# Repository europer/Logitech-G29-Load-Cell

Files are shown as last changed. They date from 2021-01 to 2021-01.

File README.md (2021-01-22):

# Logitech-G29-Load-Cell

I will not repeat the text what you can find in the "References" and keep the story short:

My ideas to develop this program was due to the inspiration and using the ideas of the References:

# References
1) https://github.com/GeekyDeaks/g29-load-cell (original idea did come from here)
2) https://github.com/Skidude88/Skidude88-G29-PS4-LoadCell-Arduino/wiki (original idea did come from here)
3) https://github.com/olkal/HX711_ADC (library for the HX711 I did use)
4) https://github.com/iforce2d/thrustTester (to get the default setup of the HX711 from 10 to 80 Hz, my HX711 did end up with 89 Hz)
5) https://circuitjournal.com/50kg-load-cells-with-HX711 (wiring with 2 cells)
6) https://www.youtube.com/watch?v=iywsJB-T-mU (at 7:15, due to ESP32 speed)
7) https://www.youtube.com/watch?v=99u9cy7Mnl4 (for mod the rubber to simulate more like a load cell)
8) Google Store: Serial Bluetooth Terminal from Kai Morich
9) Gamma Calculation: https://www.desmos.com/calculator/swnathc6og

and I will not refer it more in the text, since it is a mix overall and all of them above did contribute to my result.

The reason for this is that the G29 use pot.meter from 0-100% break over distance => give the output voltage to regulate corresponding break %.
The force feedback from the spring is more or less linear and at the end we touch a rubber what will simulate a higher pressure but for the muscle memory is difficult to memorize the breaking point/level/force to get a constant good breaking especially in trail breaking is difficult. 
With a load cell we are simulating closer to real hydraulic breaks in real life where we need over proportional force curve to reach higher break.

Then the G29 and PS4 do not give any possibilities to trim the break to your driving style and this was also one of my reason to have a micro controller so that I could manipulate the output values to fit my braking conditions.

# Shopping List:
1) Load Cells with HX711 
2) Micro controller 
3) Enclosing for the Micro Controller/HX711 and for the Load Cells
4) Resistors (500 and 220 Ohm) and cables

# How-to and why

To use PWM signal to generate the needed voltage range was not good if not using a low filter or a DAC. Since I am using ESP32 anyway to other Arduino projects and they are cheap (at Amazon go under 6 Euro, included delivery) is a very unexpensive MC.

The advantage:
1) rel. fast 2xCPU with 32 bits
2) 2 x8 bit DAC (range 0-255)
3) Bluetooth for serial com. for changing parameters in the setup/trimming the break
4) Voltage range 0-3.3V fits anyway to the G29 what also is in this range

That was the reason to use ESP32 and as I was work with the project I wanted to "simulate" a "PWM" with my DAC between 2 values and here the multitask function of the ESP32 was perfect, letting the main program calculate the values for breaking and if a needed value was between, let’s say 231 and 232 I would let the DAC jump between 231 and 232 in an constant loop (of course calculated how many times of 231 and 232 to get the right simulated value let say 231.12) so in this case the task would not have any "delay" but just looping and looping with the latest known values until the task did get new values. Fantastic the ESP32 :)

Another issue known is that the G29 let’s say your breaking at 80% distance on the break is not equal to 80% in your PS4. G29 have an over exponential curve and I had to find out the values so that I could do a linearization of the curve (also my references are referring about this issue). After finding 0% break and 100% I had the outer points (min/max). So, 50% must be between, well was not as explained above. How to find 50%? I did find the bit value what was correspond to 50% in the game. Let’s say 0% was 210 and 100% 140 => (140+210)/2 = 175 in the DAC as bit but was not. So, you then change the bit value until you get the 50% in the game (look at the TV/Monitor and adjust the bit value until you see the column reach 50% in my case GT Sprot). So now the work was to check for many different %-point between 0 and 100% after this I could make a load array, you could also use a function but is quicker to use points in an array and calculate the output between 2 points.

Then I wanted to have a gamma factor to adjust the bias of the curve to fit my way of breaking. 
G>1.0 means that the break% is increasing over proportional, G<1.0 the opposite. G = 1 linear.

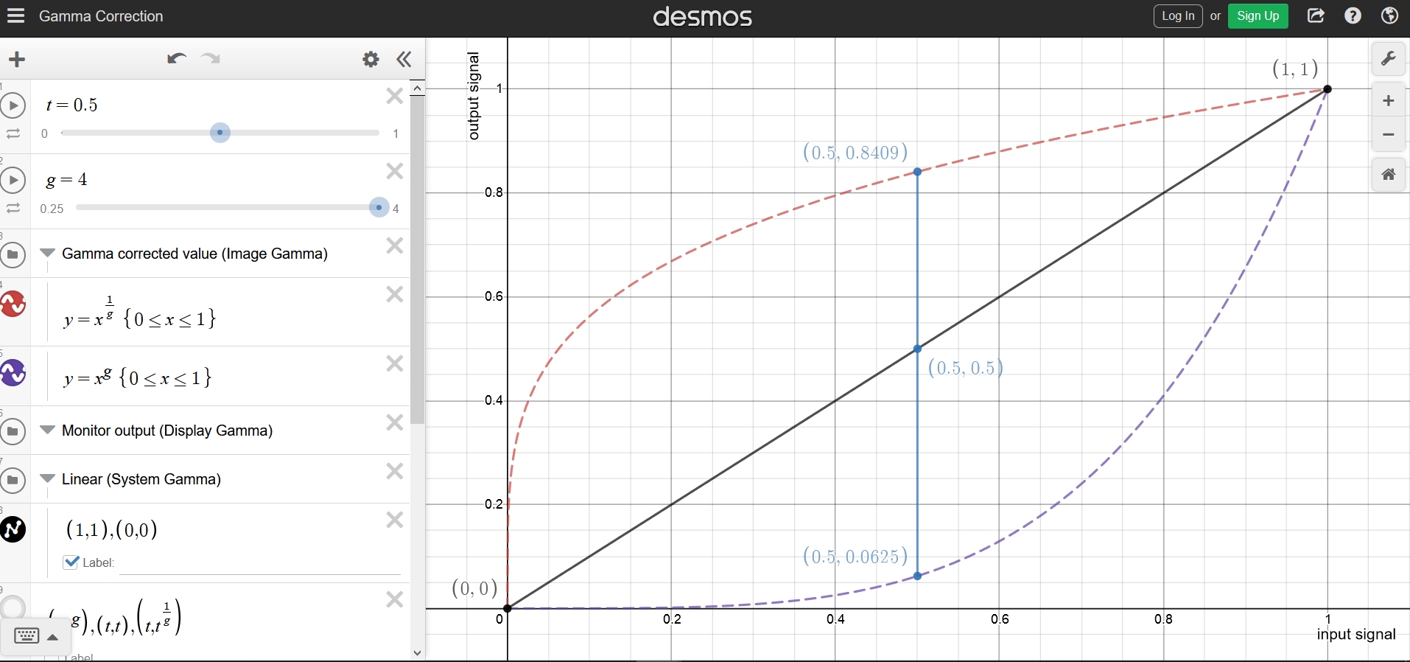
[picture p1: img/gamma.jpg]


Pic. 0) see References #9, Gamma Calculation: https://www.desmos.com/calculator/swnathc6og. 
Red dotted line gamma = 4, Blue dotted line gamma = 0.25 and black line gamma = 1 = linear

Then the break needed a dead zone, means your break don’t start at zero Kg but at example 0.2 Kg.
Then the break needed a max load = 100% break, so if you hit the break more than max load => 100% break.
Then I did read in IRacing that the max load = 100% could be reduced to a %, let’s say 80%, means if you break at max load = 100% (normally) it would be 80%, so I also implemented this (never know if I will do IRacing but anyway good to have).
Then I wanted to send over the air serial commands to the ESP32 to change parameter for my breaking if trimming was needed during the race (rather between the race or qualifying).
Then of course encloser for the brake system and for the ESP32/HX711 (see 3D files)

That is all in a nut-shell.

Im an engineer and not a programmer so could be that my programming is dirty, so I do not mind if somebody would pimp it up, but it works and it works like a charm.

# Circuit/Wiring/PCB

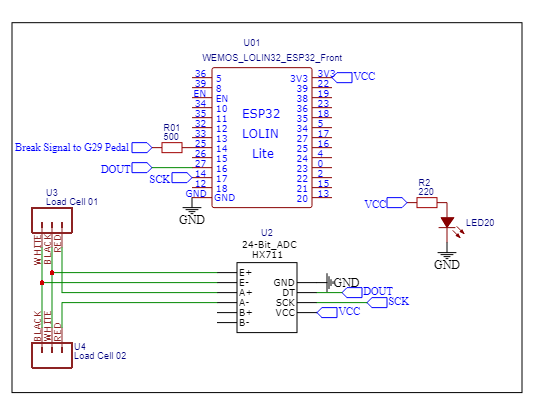
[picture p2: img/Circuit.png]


Pic. 1) See Ref. 5) https://circuitjournal.com/50kg-load-cells-with-HX711 (wiring with 2 cells)

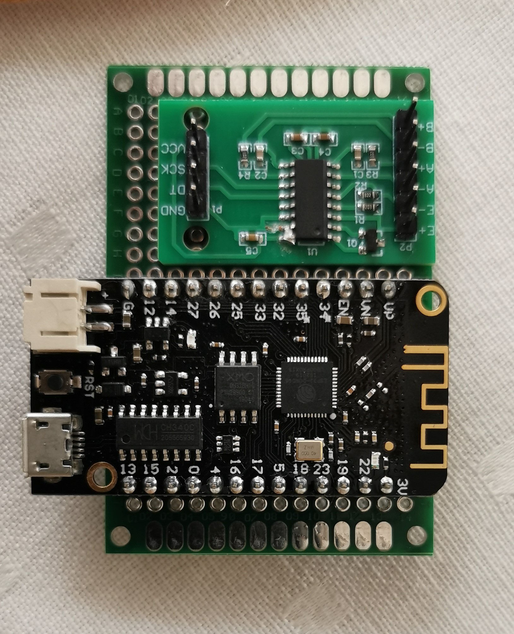
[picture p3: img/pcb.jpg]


Pic. 2) Soldering ESP32 & HX711 on a small PCB, wiring after circuit diagram (see Pic. 1 above)

# 3D Print / Encloser

yes, I know old filament so not the nicest but did work perfect anyway ;)

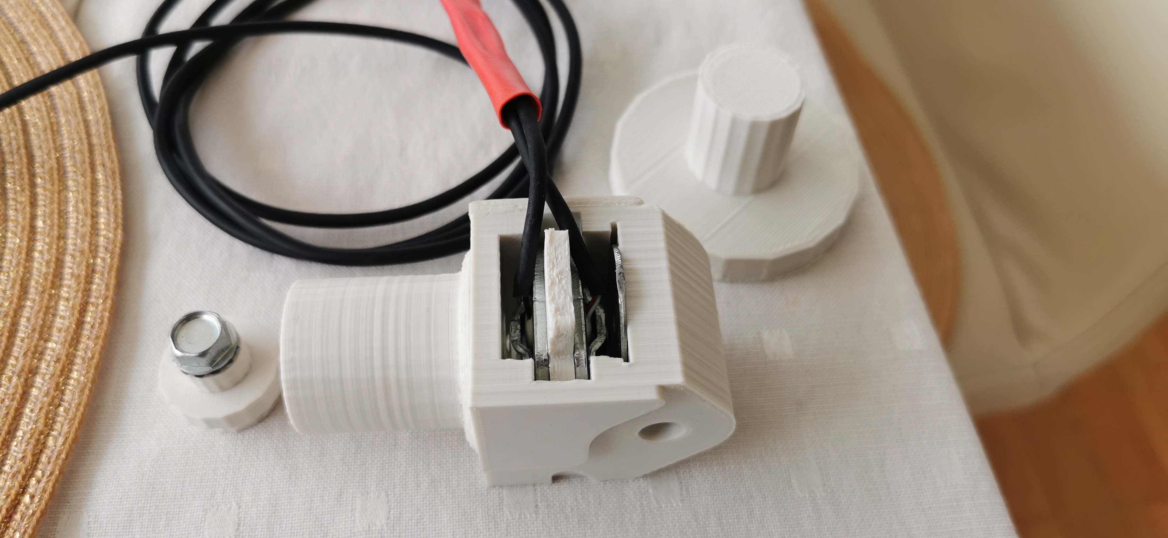
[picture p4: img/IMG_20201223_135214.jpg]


Pic. 3) left part: plunger what is pushing the load to the load cell, mid part = encloser for the 2 load cells, right part = calibrator (see Pic. 4)

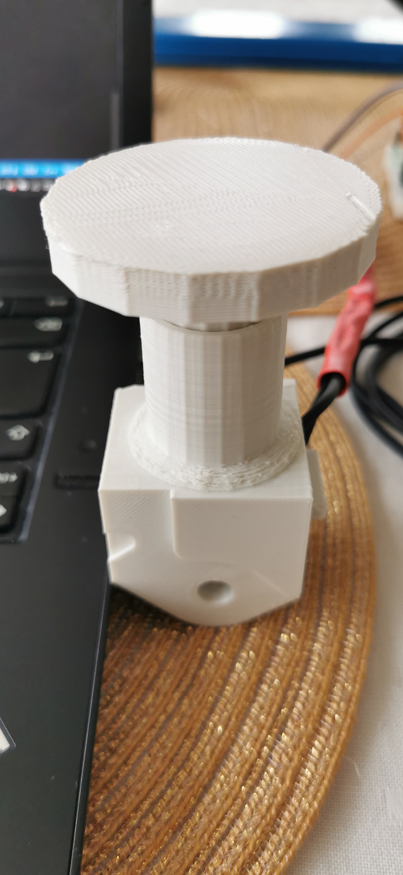
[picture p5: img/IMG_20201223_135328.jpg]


Pic. 4) the Calibrator is just to have a platform to put load on as one-time calibration for weight. I did use 2x1Kg as reference 

# STL Files for the Break and for the ESP32 Box:

See folder STL_BREAK and STL_BOX:
https://github.com/europer/Logitech-G29-Load-Cell/tree/main/STL_BOX
https://github.com/europer/Logitech-G29-Load-Cell/tree/main/STL_BREAK

# Linearization Results:

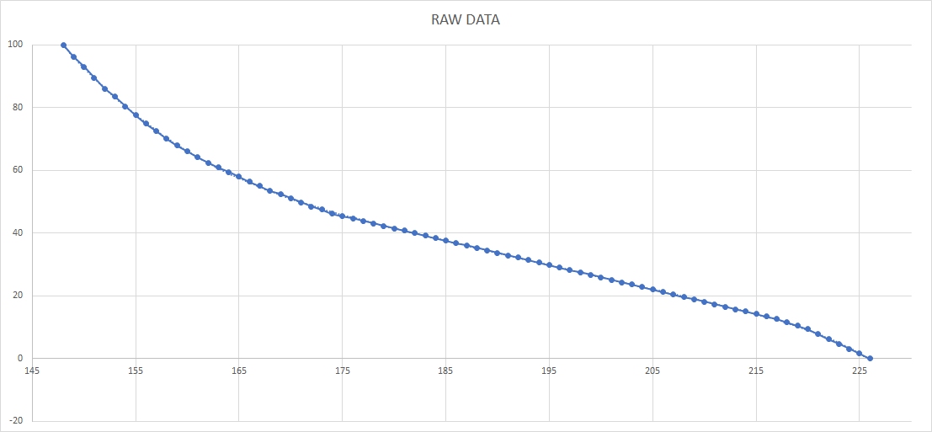
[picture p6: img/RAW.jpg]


Pic. 5) The result of the raw data in a diagram. Y: Break force [%] X: Voltage in 8 Bit (0-255 = 0-3.3V)

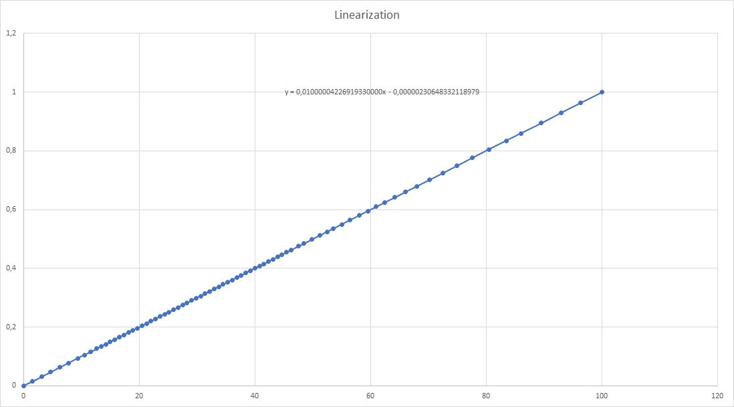
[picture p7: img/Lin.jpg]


Pic. 6) From Pic 5 the Load was linearized (from 0-1 and 0-100%) so that 50% load input = 50% break in game.

The load array (is in the Arduino program) resulted into the following load array with 79 points:

float load_percent[79] = {1.0, 0.963, 0.93, 0.895, 0.86, 0.835, 0.804, 0.776, 0.749, 0.725,
                          0.701, 0.68, 0.66, 0.642, 0.625, 0.609, 0.595, 0.58, 0.564, 0.55,
                          0.535, 0.525, 0.512, 0.498, 0.485, 0.475, 0.462, 0.455, 0.447, 0.439,
                          0.431, 0.423, 0.416, 0.408, 0.4, 0.392, 0.384, 0.377, 0.369, 0.361,
                          0.353, 0.345, 0.337, 0.33, 0.322, 0.314, 0.306, 0.298, 0.291, 0.283,
                          0.275, 0.267, 0.259, 0.252, 0.247, 0.236, 0.228, 0.220, 0.212, 0.205,
                          0.197, 0.189, 0.181, 0.173, 0.166, 0.158, 0.15, 0.142, 0.134, 0.127,
                          0.116, 0.105, 0.094, 0.078, 0.063, 0.047, 0.031, 0.016, 0.0};
                          
How to understand this:
We have after calibration the min and max point/break: 
min break = 147 and max break = 227 in voltage this again correspond to a weight from your load cell, let’s say:
min break = 1.0 Kg and max break = 10.0 Kg.

We now map the input (what is the kg) to output what we need to as voltage out to correspond to the weight/force:

Let’s say we are pushing with a force of 5.5 kg.

In the program this we use the mapping function:
Syntax: mapping(weight in,min break kg, max break kg, min output, max output). //own function, yes you can use the map what Arduino have, but sometimes I like my own routines.

weight_in_percent = mapping(5.5, 1.0, 10.0, 0.0, 1.0) and yes output will be 0.50 in this case ;).

From the load_percent array 0.50 is between nr 22 = 0.512 and nr 23 = 0.498 (counting with 0 as first value), the program will loop trough the array to see where weight_in_percent. 
The laod_perecent range is 79 points and the max/min break from 147 to 227 = 80, not same steps so we need to map this too.

lower = mapping(22, 78, 0, 227, 147) = 170.
upper = mapping(23, 78, 0, 227, 147) = 169.

Mean when the ESP32 send a DAC with the bit 170 and 169 we would get 50% break load, without the linearization the program would send out (147+227)/2 = 187 to DAC.
If we look at Pic. 5 this would result into approx. 37% breaking and not 50%.

The program calculates out of 10 how many times it must be lower and upper so that the task (FreeRTOS) to "simulate" a PWM between 2 DAC signal. 
In this case it would be 8 times 170 and 1 time 169 due to rounding.
If there is no new update from the load cell or/and the load value is the same it will just loop and loop these values until new values comes in.
Since this task operate without interference there are no timer since the task will be relative constant in time and performance.
Later in text you can see a short video from the oscilloscope and simulate a sinus curve and we will see that for this application is more the good enough.

In Arduino, DAC1 = Pin 25 for ESP32 (see ESP32 reference, DAC1 = 25, DAC2 = 26):.
dacWrite(DAC1, 170); x 8 times. 
dacWrite(DAC1, 169); x 1 time.

In this video (sorry was a video for my father-in-law and he is a master in electronic and it was in Norwegian).
we see the first part with Gamma factor = 1 (linear) then with Gamma 4.0 and then with Gamma = 0.25.

https://github.com/europer/Logitech-G29-Load-Cell/blob/main/img/Osci.mp4

# AoB

I did cut the outer valve 10mm because due to shorter distance due to the new inner valve (where the load cell is installed into) takes space in direction to the pedal I personally needed 10mm more. 
I did also increase the original rubber as in Reference 7) https://www.youtube.com/watch?v=99u9cy7Mnl4 (for mod the rubber to simulate more like a load cell).
Here you need to find your length of the rubber you need, I did increase my new "rubber" so that I had 1,5times the length from the original, but after cutting the 10mm above it was then to short, rather 2times would be better. The reason is very weak spring, first when I hit the rubber the weight goes high. I do compensate this with a Gamma of 1.8 but I will further change the spring to a lot stiffer version. This part everybody needs to find at its own and I can’t give any preference what is good or bad, since this is individual.

Regards the libary, in PlatformIO my local libaries are (default) in hidden folders, so as I did upload everything thouse files did not go into my github, therefore I did save them in the folder "lib". You just download them and put it where you need it in you libary system, you need perhaps to change the #inlcude from "....." to #inlcude from <.....> and then it should work for all IDE's

Did it help me, YES, my lap time did reduce in average up to 3 sec and not just that, my laps are constant, less errors in general, so for around 15 Euro investment a great update, I think the best update you can do for sim racing!!!

# Using the serial commands

over USB or BT, see Reference 8) Google Store: Serial Bluetooth Terminal from Kai Morich.
1) t = for TARA the load cells.
2) c = for calibrate the load cell, pushing pedal to your desired max break and 2nd push for min break.
3) v = for voltage calibration (max break and min break, it use the dacWrite(DAC1, wanted bit for min or max break)).
4) e = read out the storage values in the eeprom since mostly we will not change values and just play the game when we have the wanted parameter ;).
5) a = read out what is in RAM at given time, if you use "e" to read out eeprom it will change the values in the RAM if they could be different, since you dont need to save new values!!!.
6) w = in BT-App and www = at direct conection between ESP32 and PC. Here we calibrate the load cell with known load, use the calibrator (see Pic. 4) and put know load on it, I was using 2x1kg manuall weights, but you can also use a liter of water, or 1 kg Sugar, what ever. This is just to know for your interesst what is acctually the load in Kg but is not needed, but you need to but a value here for the first time. If you dont have a refrence value push a bit, and give 1000 in (what would be normaly 1000g=1kg).
7) s = to have serial output of the load your have at given time (every 1 sec an new serial.print).
8) l = here you can fine tune your 'c' directly into kg (max/min).
9) r = reboot the ESP32.
10) n = using the raw data or noralisation with gamma factor.
11) i = simulate 1=sinus curve, 2=0,25,50,75,100% load and default is 0 what is the load cell itself.

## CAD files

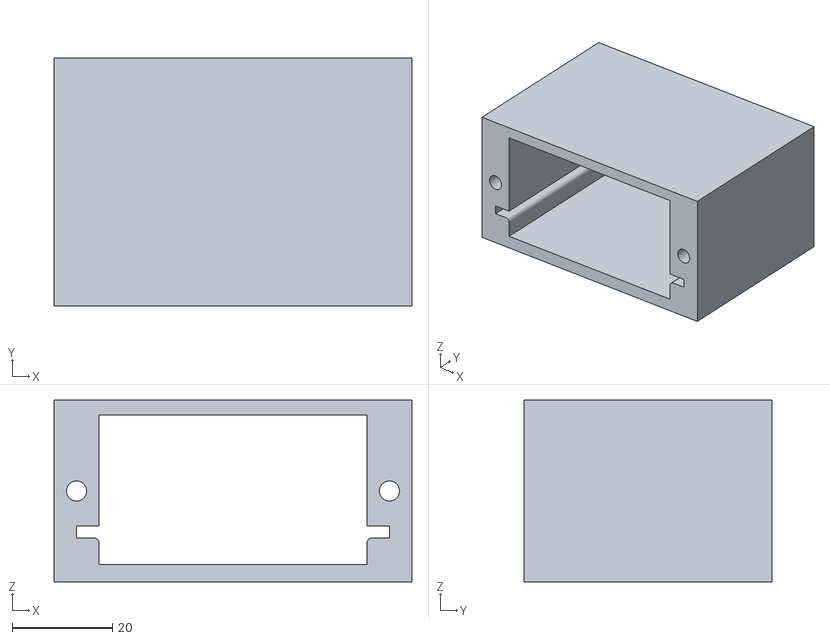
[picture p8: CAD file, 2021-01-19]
STL_BOX/Box_Main_V02.stl
71.5 x 49.6 x 36.3

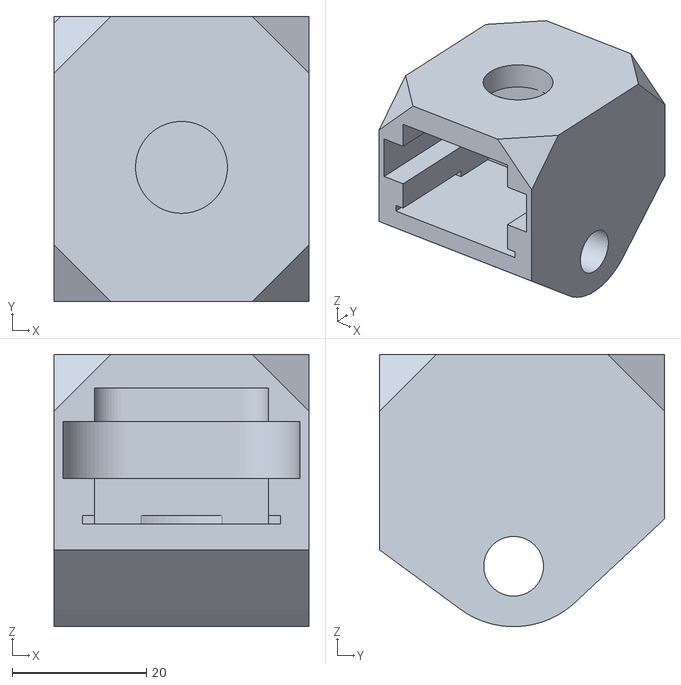
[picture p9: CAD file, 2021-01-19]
STL_BREAK/main_body_V06.stl
38.0 x 42.5 x 40.6

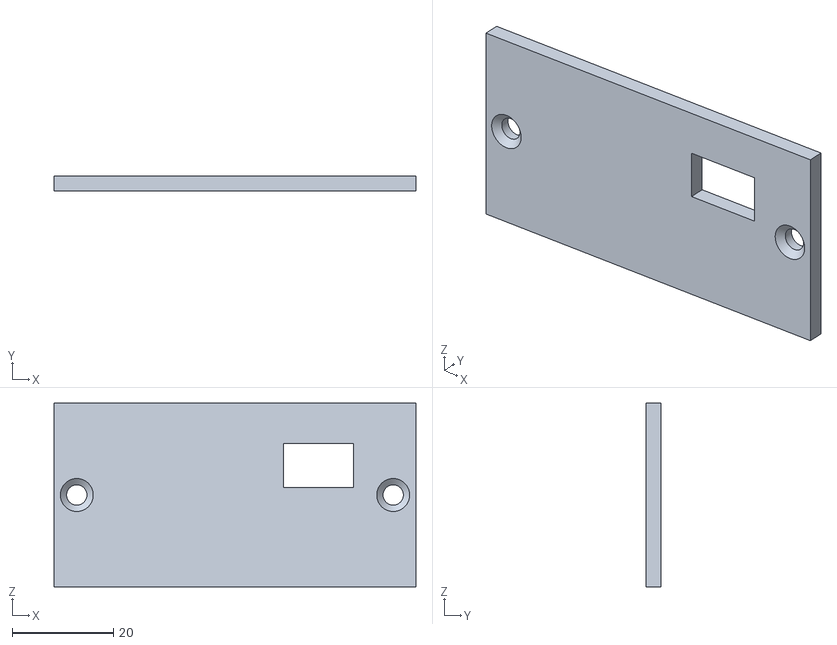
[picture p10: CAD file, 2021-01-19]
STL_BOX/Box_Front.stl
71.5 x 3.00 x 36.3

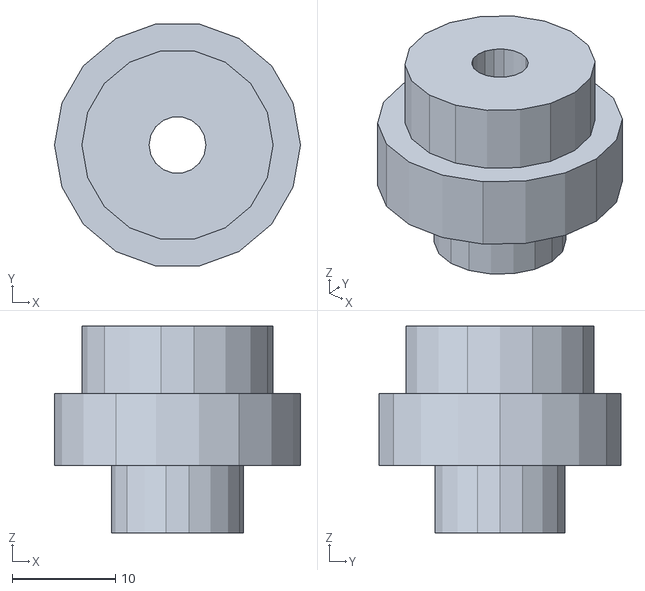
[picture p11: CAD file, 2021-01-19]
STL_BREAK/plunger.stl
23.8 x 23.4 x 20.0

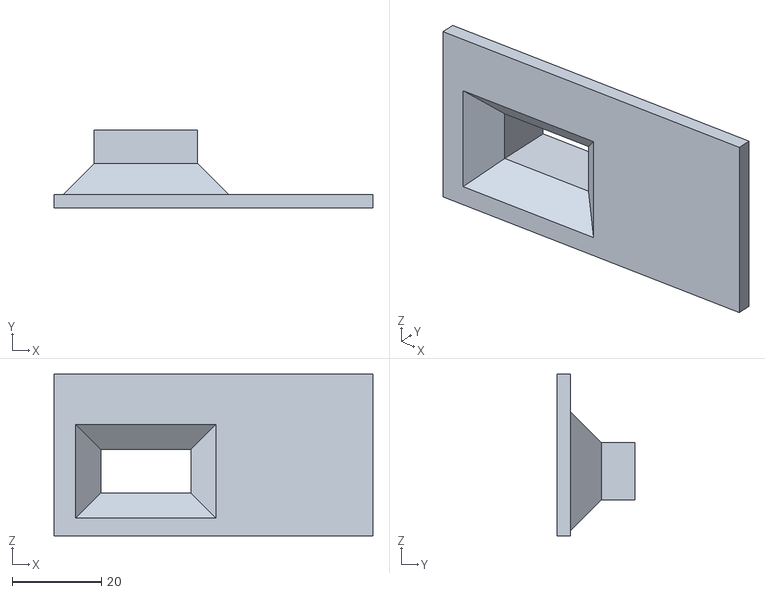
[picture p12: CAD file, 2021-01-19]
STL_BOX/Box_Back_V03.stl
71.5 x 17.5 x 36.3

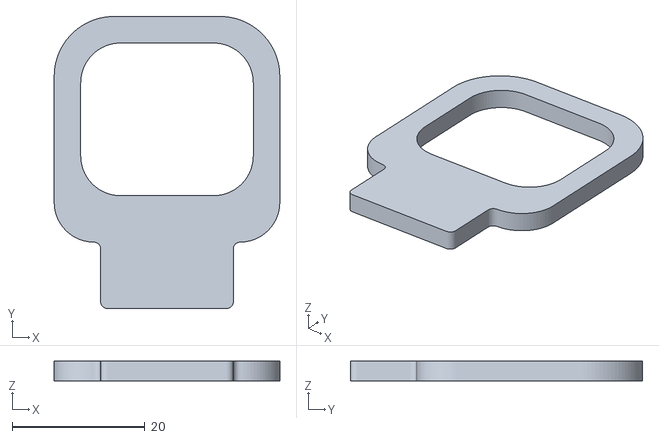
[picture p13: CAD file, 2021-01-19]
STL_BREAK/spacer_V06.stl
34.0 x 44.0 x 3.00

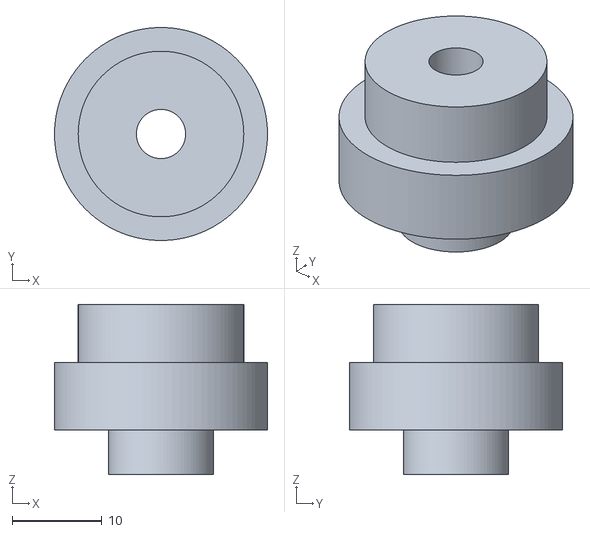
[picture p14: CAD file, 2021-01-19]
STL_BREAK/plunger_V07.stl
23.8 x 23.8 x 19.0

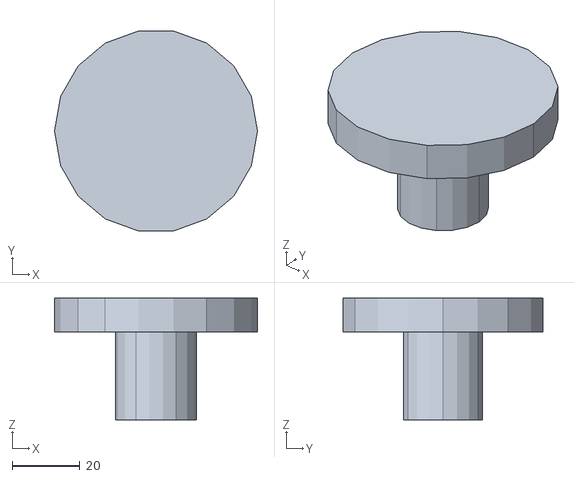
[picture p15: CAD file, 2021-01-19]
STL_BREAK/calibrator.stl
60.0 x 59.1 x 36.0

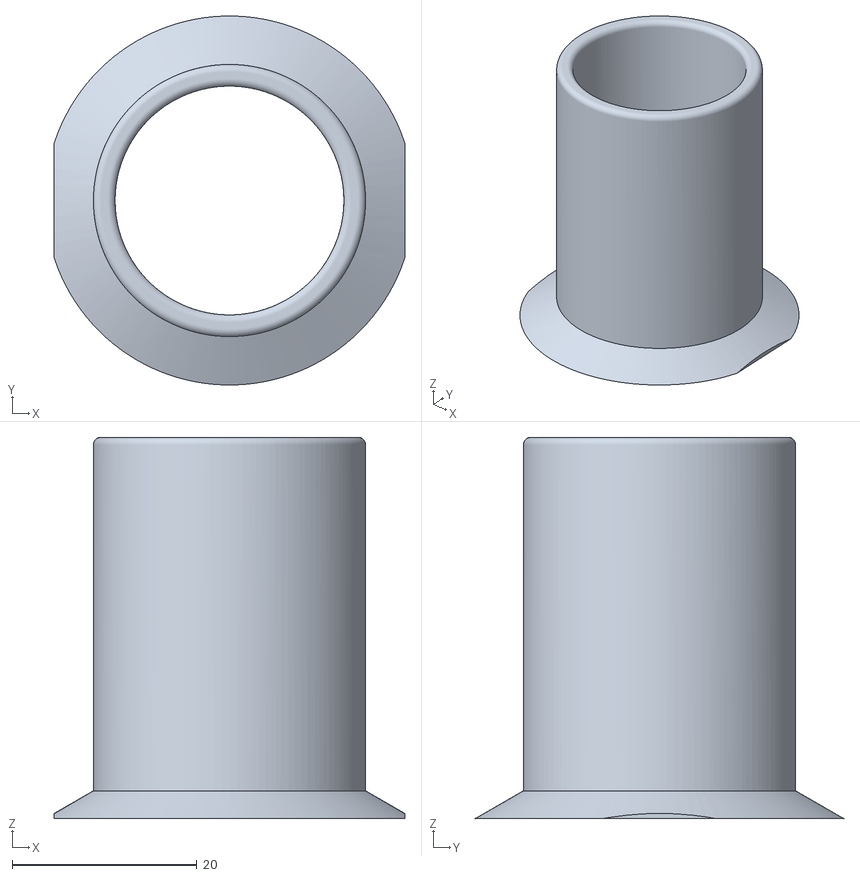
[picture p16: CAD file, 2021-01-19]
STL_BREAK/cylinder_V06.stl
38.0 x 40.0 x 41.4

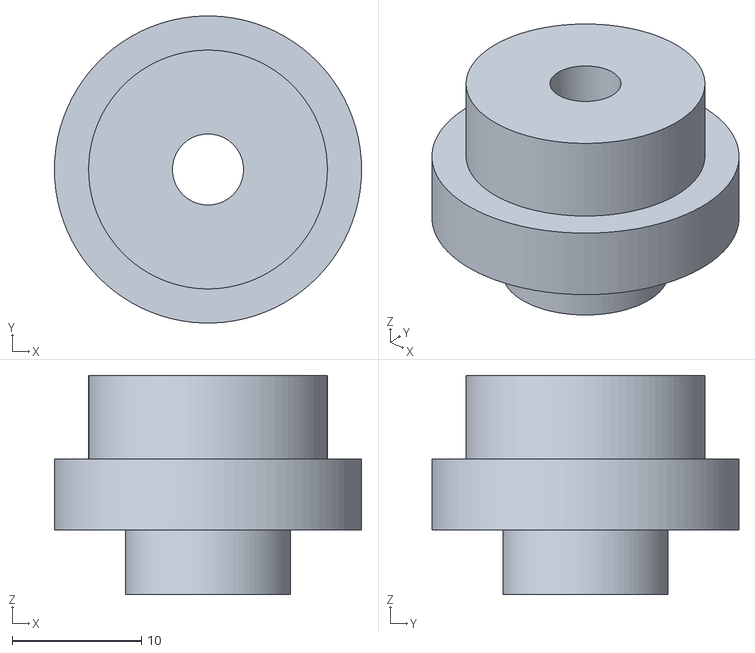
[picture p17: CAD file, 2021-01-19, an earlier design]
STL_BREAK/plunger_V06.stl
23.8 x 23.8 x 17.0

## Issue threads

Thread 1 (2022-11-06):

How to asseble printed parts?

freestaila, 2022-11-06:
Hi!

First of all I would like to thank you for sharing this awesome project!
I have a questions about this printed files.
1. One part of the box have holes for screws. The bottom one don't. I should glue this bottom part or just need to drill this holes manually?
2. The center part - cylinder is separrated part. On other projects this is one part with this main part for cells. Is it only for first calibration and I should only use this part with screw to make pressure for cells? I'm not sure how to mount this to the origin setup.

Thanks for the answers!

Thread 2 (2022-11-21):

Function calicalulation_break() no return

freestaila, 2022-11-21:
Hi!

Inside `calicalulation_break()` function return is missing for calc_type 1.
That causing problem with calibrate function. After put value for max break point program breaks.

europer, 2022-11-22:
Hi,
the code I did write for x years back so I am not more into it, but will have a look and see if the uploadet data here in github is the same as on my ESP32 and come back to you if its a quick fix for this issue.
BR

europer, 2022-11-22:
I had a very brief look at the code, surly now I would code it a bit differently but never the less it should work also without return.If you need to but a return just put reutrn -10 or a integer, since the only thing what I wanted with this function was this:
int calicalulation_break(float &value2change, float value2compare, int flag2compare, int calc_type)
and what I want is the "float &value2change" back from the function. I passed the value into function, the return value have no meaning.
I could be at calibration the value from you system is not ok. In case of case 1 you need to be between max and min load at least 90% so that the min value is lower and also min<max*90%. Have you checked the load data from your load cell?

But again, if you but some returns into the code for the case 1 (as in case 2) and this makes the calibration correct, then its fine.

Again, I will look at my last code in my pc and see if this is the same version as into github

cheers

europer, 2022-11-22:
ok, I would change the function today like this:

int calicalulation_break(float &value2change, float value2compare, int flag2compare, int calc_type)
{
the code of the functuon
and extra at the end of the function
return -1;
}

what ever reason after all "if" and no conditions are meet or no return at least one return will be trigger.
since the return value have no meaning, could be as I was programming that time I had an idea of something. I mean it could also be a void function but never the less just put a return (int) at the end of the function.
In the main program the function is never uses like this (example)

returnvalue = calicalulation_break(maxbreak, 0, 0, 1);

but just like this:
calicalulation_break(maxbreak, 0, 0, 1); becasue I just wantend the (in this case) the maxbreak value as "return"

I hope this helped (not forget was my first project and I am not a c/c++ expert ;) ) so surly dirty coding ;)
(but did work without problems all the years, perhaps luck? ;) )

freestaila, 2022-11-22:
@europer thanks for the answer. I already fixed it for me and I have proper calibrations values. All set up with cells and esp32 works good for now.

I don't know why but after connecting board to logitech wires- it seems like unstable power connection. Light on board switcing off and on second by second. I connected 2 reds and 2 blacks to micro usb cable.

Of course this code is not perfect but works! Thats matters. Hope I will finish my setup soon.

freestaila, 2022-11-22:
One more question.
I connected to Logitech brake wires micro USB cable to provide power to board. But without USB I have 3.3v output after connect via USB to board I have 1.7v. Do you connected power wires to board directly?

europer, 2022-11-24:
Good question and I see I have formulated less here in my GitHub. But here how I did it. My esp32 get power from a usb adapter. All pedals got the power normal from Logitech, just the break got the signal from the esp32, but common earth (of course) so you have look at the potensometer on break and take the signal line to esp32 setup. So the esp32 setup is the new potesiometer. I hope you got me?
BR

europer, 2022-11-24:
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

europer, 2022-11-24:
There is 3 cables at the break. 1) VCC u don't need 2) output cable you need to connect to output signal on esp32 and 3) ground  cable on pedal and esp32

freestaila, 2022-11-24:
Ground only need to be connected to esp32? Or both to the brake and ESP?

freestaila, 2022-11-24:
Output is white? Now when I use throttle brake also works hahah

freestaila, 2022-11-24:
And brake no

europer, 2022-11-24:
Do u have voltmeter, chech where the 3.3v and where the signal line is on the potensometer. Regards ground, so long you use the ground cable what was on the pedal to connect to esp32 ground it would be enough but the pedal have lot of mass so I just mean it the better ground, but is not necessary because the cable is anyway ground from Logitech

europer, 2022-11-24:
Strange, check all connection not that you have some connections to trottle, chech also it the contact from pedal into the wheel is properly in. Check also you esp32 output makes voltage between 0-3.3v. it's just a intelligent potensometer where you can manipulate values. It is really nothing else

freestaila, 2022-11-28:
When normalization is set to 0 all looks good. When I change this to 1 then my values on serial are good for weight but Voltage is always = 3.3V. Something goes wrong inside calculation for nromalization.

europer, 2022-11-30:
It's strange since it works flawlessly on my esp32
I can't say what it is.
Chech without the Normalisation and if u push break to 50% (that time it was on GT sport) your game your playing what is the result.
You need to calibrate your cells to your game.
You need to know at witch voltage zero break is.
You need to know at witch voltage at 100% break is.
So if you know this you know that between 0 and 100% where the voltage for 50% what should be 50% breaking force but mostly this will not be in the game. Therefore we do the Normalisation. To recalc that when we "push" 50% you get 50% in the game but as in my test in GitHub you need check if this fits for your game, load cell ..
BR

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

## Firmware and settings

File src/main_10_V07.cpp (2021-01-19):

#include <Arduino.h>
#include <math.h>
/*
   -------------------------------------------------------------------------------------
   HX711_ADC
   Arduino library for HX711 24-Bit Analog-to-Digital Converter for Weight Scales
   Olav Kallhovd sept2017
   -------------------------------------------------------------------------------------
*/

/*
   This example file shows how to calibrate the load cell and optionally store the calibration
   value in EEPROM, and also how to change the value manually.
   The result value can then later be included in your project sketch or fetched from EEPROM.

   To implement calibration in your project sketch the simplified procedure is as follow:
       LoadCell.tare();
       //place known mass
       LoadCell.refreshDataSet();
       float newCalibrationValue = LoadCell.getNewCalibration(known_mass);
*/

//own local libaries
#include "string2char.h"    //convert string to char
#include "bit_check_band.h" //check if a value is within the min max if lower=min, if over=max
#include "mapping.h"        //map a input value to a new range out

// external libaries
#include <HX711_ADC.h> // the libary for the HX711
#include <EEPROM.h>    //Libary for the EEPROM Memory
#include <BluetoothSerial.h>

#if !defined(CONFIG_BT_ENABLED) || !defined(CONFIG_BLUEDROID_ENABLED)
#error Bluetooth is not enabled! Please run `make menuconfig` to and enable it
#endif

BluetoothSerial SerialBT;

TaskHandle_t Task0;
//TaskHandle_t Task1;
//QueueHandle_t queue;
SemaphoreHandle_t Semaphore;

//pins:
const int HX711_dout = 27; //mcu > HX711 dout pin
const int HX711_sck = 14;  //mcu > HX711 sck pin

//DAC output
#define DAC1 25 // Break Voltage Out to PS4/PC

//HX711 constructor:
HX711_ADC LoadCell(HX711_dout, HX711_sck);

const int calVal_eepromAdress = 0;
long t;

long t_simulate;
int flag_init_time = 1; //1=true
int case_counter = 0;

String ino = __FILE__; //file name

bool volt_direction_normal = false; // break 0-100% voltage low-hight = true

float max_break = 21.23f;
float max_break_redfac = 100.00f; //if max break to much reduce here in %
float min_break = 1.43f;

//max voltage in esp32 is 3.3volt and adjust the break in the PC/PS4
/*
  GTSport
  break 0% - 2.86v = 221
  break 100% - 1.93v = 149
  Assetto Corsa Comp
  break 0% - 2.88v = 222-223
  break 100% - 1.48v = 114
*/
int min_break_volt = 221;
int max_break_volt = 149;

int minbit = 0;
int maxbit = 255;

float esp32Volt = 3.3;

float ref_voltage = (1.0 / 255.0) * esp32Volt;

float newCalibrationValue = 1.23f;

float kg_factor = 1000.0f;

int SerialPrintData = 0; //no Serial Printout of Data

bool reboot_esp32 = false;

int simulant_case = 0; //no simulation just the load cell, Sinus curve = 1, na=2, na=3

float gammafac = 1.0; //linear
int laod_percent_steps = 79;
float load_percent[79] = {1.0, 0.963, 0.93, 0.895, 0.86, 0.835, 0.804, 0.776, 0.749, 0.725,
                          0.701, 0.68, 0.66, 0.642, 0.625, 0.609, 0.595, 0.58, 0.564, 0.55,
                          0.535, 0.525, 0.512, 0.498, 0.485, 0.475, 0.462, 0.455, 0.447, 0.439,
                          0.431, 0.423, 0.416, 0.408, 0.4, 0.392, 0.384, 0.377, 0.369, 0.361,
                          0.353, 0.345, 0.337, 0.33, 0.322, 0.314, 0.306, 0.298, 0.291, 0.283,
                          0.275, 0.267, 0.259, 0.252, 0.247, 0.236, 0.228, 0.220, 0.212, 0.205,
                          0.197, 0.189, 0.181, 0.173, 0.166, 0.158, 0.15, 0.142, 0.134, 0.127,
                          0.116, 0.105, 0.094, 0.078, 0.063, 0.047, 0.031, 0.016, 0.0};

float rad = 0.0; //zero angle

int normal = 1; // 2 = use input as output (raw with oth load_percen array), 0 = in voltage

// Global variables, available to all
static volatile unsigned int lowerbitcase;
static volatile unsigned int upperbitcase;
static volatile unsigned int lower2pwm;
static volatile unsigned int upper2pwm;
static volatile bool open2use = false;
static volatile unsigned long count = 0;
static volatile int normalization = 1;
static volatile float GLED_global;
static volatile int dac_case_global;

void print_serial_and_bt(String text2print, int newlineornot)
{
    if (newlineornot == 0)
    {
        Serial.print(text2print);
        SerialBT.print(text2print);
    }
    if (newlineornot == 1)
    {
        Serial.println(text2print);
        SerialBT.println(text2print);
    }
}

void pause_multitask()
{
    //This is just during when we interact with the program with commands (serial commands)
    //until we are not finished the process with the commands the program stop the task

    //give the normalization = 2 => pause
    xSemaphoreTake(Semaphore, portMAX_DELAY);
    normalization = 2; //turn of multi task part of voltage in pwm2dac function
    open2use = true;
    xSemaphoreGive(Semaphore);
    vTaskDelay(200); //0.2mil sec delay

    //tell multitask not to take variables
    xSemaphoreTake(Semaphore, portMAX_DELAY);
    open2use = false;
    xSemaphoreGive(Semaphore);
}

void restart_multitask()
{
    //This is just during when we interact with the program with commands (serial commands)
    //until we are not finished the process with the commands the program stop the task

    //tell multitask to take variables again an set normal back to original 0 or 1
    vTaskDelay(3000); //3 sec delay
    xSemaphoreTake(Semaphore, portMAX_DELAY);
    normalization = normal; //give back the normal 0 or 1 (0=raw input != output on G29, 1=adjusted so that 50% load in = 50% load out)
    open2use = true;
    xSemaphoreGive(Semaphore);
    vTaskDelay(200); //3 sec delay
}

void SDPrint()
{
    Serial.flush();   //clean buffer
    SerialBT.flush(); //clean buffer

    print_serial_and_bt("***", 1);
    print_serial_and_bt("SerailDataOutput?", 1);
    print_serial_and_bt("Send 'y' or 'n'", 1);

    boolean _resume = false;
    while (_resume == false)
    {
        LoadCell.update();
        if (Serial.available() > 0 || SerialBT.available())
        {

            char inByte = Serial.read();
            char BTByte = SerialBT.read();
            if (inByte == 'y' || BTByte == 'y')
            {
                SerialPrintData = 1;
                _resume = true;
            }
            else if (inByte == 'n' || BTByte == 'n')
            {
                SerialPrintData = 0;
                _resume = true;
            }
        }
    }
    Serial.flush();   //clean buffer
    SerialBT.flush(); //clean buffer
}

void simulation_esp32()
{
    Serial.flush();   //clean buffer
    SerialBT.flush(); //clean buffer

    print_serial_and_bt("***", 1);
    print_serial_and_bt("Simulate load cell load?", 1);
    print_serial_and_bt("0: real load cell", 1);
    print_serial_and_bt("1: sinus curve", 1);
    print_serial_and_bt("2: 100,75,50,25,0 % curve", 1);
    print_serial_and_bt("-1: no changes", 1);

    boolean _resume = false;
    while (_resume == false)
    {
        LoadCell.update();
        if (Serial.available() > 0 || SerialBT.available())
        {

            char inByte = Serial.read();
            char BTByte = SerialBT.read();
            if (inByte == '0' || BTByte == '0')
            {
                simulant_case = 0;
                _resume = true;
            }
            else if (inByte == '1' || BTByte == '1')
            {
                simulant_case = 1;
                _resume = true;
            }
            else if (inByte == '2' || BTByte == '2')
            {
                simulant_case = 2;
                _resume = true;
            }
            else if (inByte == '-1' || BTByte == '-1')
            {
                _resume = true;
            }
        }
    }
    Serial.flush();   //clean buffer
    SerialBT.flush(); //clean buffer

    print_serial_and_bt("***", 1);
    print_serial_and_bt("case was used: ", 0);
    print_serial_and_bt(String(simulant_case), 1);
}

void reboot_mc()
{
    reboot_esp32 = true;
}

void tara_load_cell()
{
    print_serial_and_bt("***", 1);
    print_serial_and_bt("Tara started", 1);

    LoadCell.update();
    LoadCell.tareNoDelay();

    print_serial_and_bt("Tara finished", 1);
    print_serial_and_bt("***", 1);
}

void load_variables_eeprom(int ja_nein)
{

    if (ja_nein == 1) //from EEPROM = 1, and from RAM = 0
    {
#if defined(ESP8266) || defined(ESP32)
        EEPROM.begin(512); // uncomment this if you use ESP8266/ESP32 and want to fetch the calibration value from eeprom
#endif
        int temp_adress = 0;
        EEPROM.get(calVal_eepromAdress, newCalibrationValue);
        LoadCell.setCalFactor(newCalibrationValue); // set calibration value (float)

        temp_adress += sizeof(newCalibrationValue);
        EEPROM.get(temp_adress, max_break); //get  max break

        temp_adress += sizeof(max_break);
        EEPROM.get(temp_adress, min_break); //get also mix break

        temp_adress += sizeof(min_break);
        EEPROM.get(temp_adress, max_break_redfac); //get also max reduced break factor

        temp_adress += sizeof(max_break_redfac);
        EEPROM.get(temp_adress, max_break_volt); //get also max voltage

        temp_adress += sizeof(max_break_volt);
        EEPROM.get(temp_adress, min_break_volt); //get also min voltage

        temp_adress += sizeof(max_break_redfac);
        EEPROM.get(temp_adress, normal); //Save also max break

        temp_adress += sizeof(normal);
        EEPROM.get(temp_adress, gammafac); //get also max reduced break factor

        print_serial_and_bt("", 1);
        print_serial_and_bt("*** EEPROM Read OUT ***", 0);
    }
    else
    {
        print_serial_and_bt("", 1);
        print_serial_and_bt("*** RAM Read OUT ***", 0);
    }

    print_serial_and_bt("", 1);
    print_serial_and_bt("Max break Kg: ", 0);
    print_serial_and_bt(String(max_break / kg_factor), 0);

    print_serial_and_bt("", 1);
    print_serial_and_bt("Min break RedFac %: ", 0);
    print_serial_and_bt(String(max_break_redfac), 0);

    print_serial_and_bt("", 1);
    print_serial_and_bt("Min break Kg: ", 0);
    print_serial_and_bt(String(min_break / kg_factor), 0);

    print_serial_and_bt("", 1);
    print_serial_and_bt("calibration value : ", 0);
    print_serial_and_bt(String(newCalibrationValue), 0);

    print_serial_and_bt("", 1);
    print_serial_and_bt("Max Break Voltage: ", 0);
    print_serial_and_bt(String(max_break_volt), 0);
    print_serial_and_bt("/", 0);
    print_serial_and_bt(String(max_break_volt * ref_voltage), 0);

    print_serial_and_bt("", 1);
    print_serial_and_bt("Min Break Voltage: ", 0);
    print_serial_and_bt(String(min_break_volt), 0);
    print_serial_and_bt("/", 0);
    print_serial_and_bt(String(min_break_volt * ref_voltage), 0);

    print_serial_and_bt("", 1);
    print_serial_and_bt("normalizion : ", 0);
    print_serial_and_bt(String(normal), 0);

    print_serial_and_bt("", 1);
    print_serial_and_bt("gamma factor : ", 0);
    print_serial_and_bt(String(gammafac), 0);

    print_serial_and_bt("", 1);
    print_serial_and_bt("file name : ", 0);
    print_serial_and_bt(ino, 0);
    print_serial_and_bt("", 1);
}

int calicalulation_break(float &value2change, float value2compare, int flag2compare, int calc_type)
{

    boolean _resume = false;
    if (calc_type == 1)
    {
        while (_resume == false)
        {
            LoadCell.update();
            if (Serial.available() > 0 || SerialBT.available())
            {
                char inByte = Serial.read();
                char BTByte = SerialBT.read();
                if (inByte == 'y' || BTByte == 'y')
                {
                    value2change = LoadCell.getData(); //muss be less then max
                    if (flag2compare == 1)
                    {
                        if (value2change <= (0.9 * value2compare))
                        {

                            _resume = true;
                        }
                        else
                        {
                            print_serial_and_bt("***", 1);
                            print_serial_and_bt("To close to max break point", 1);
                            print_serial_and_bt("try again with less force", 1);
                            print_serial_and_bt("***", 1);
                            _resume = false;
                        }
                    }
                    else
                    {
                        _resume = true;
                    }
                }
                if (inByte == 'n' || BTByte == 'n')
                {
                    _resume = true;
                }
            }
        }
    }
    else if (calc_type == 2)
    {
        _resume = false;
        while (_resume == false)
        {
            if (Serial.available() > 0 || SerialBT.available())
            {

                float temp_redfac = Serial.parseFloat();
                float temp_redfacBT = SerialBT.parseFloat();

                if (temp_redfac == -1)
                {
                    _resume = true;
                    return -1;
                }
                else if (temp_redfac > 0.0f && temp_redfac <= 100.0f)
                {
                    value2change = temp_redfac;
                    _resume = true;
                    return 0;
                }

                if (temp_redfacBT == -1)
                {
                    _resume = true;
                    return -1;
                }
                else if (temp_redfacBT > 0.0f && temp_redfacBT <= 100.0f)
                {
                    value2change = temp_redfacBT;
                    _resume = true;
                    return 0;
                }
            }
        }
    }
}
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
void loop()
{
    static boolean newDataReady = 0;
    const int serialPrintInterval = 1000; //increase value to slow down serial print activity
    float loadcellraw;
    float loadcellcleaned;

    //float reduces_break;
    float GLED;

    xSemaphoreTake(Semaphore, portMAX_DELAY);
    open2use = false;
    xSemaphoreGive(Semaphore);

    //check if break 0% to 100% also the voltage goes in same direction from low-hight or hight to low
    if (max_break_volt > min_break_volt)
    {
        volt_direction_normal = true;
    }

    // check for new data/start next conversion:
    if (LoadCell.update())
        newDataReady = true;

    // get smoothed value from the dataset:
    if (newDataReady)
    {
        if (simulant_case == 0)
        {
            loadcellraw = LoadCell.getData();
        }
        else if (simulant_case == 1) //sinus curve
        {
            delay(12);                                  //12mili approx 89Herz, speed pf my hx711 (not 80 but 89 is my speed)
            simulate_loadcell_sinus_curve(loadcellraw); //makes new load
        }
        else if (simulant_case == 2) //100%, 75% , 50% , 25%, 0% and then up again to 100%
        {
            int timeperiode00 = 0;
            int timeperiode01 = 5000;
            //max time periode can just be as big as max net we have, defined through az_dynamic
            int tpmax = timeperiode01 * 9; //(100,75,50,25,0,25,50,75,100 = 9)
            float load_table[9] = {100, 75, 50, 25, 0, 25, 50, 75, 100};
            long time_delta;

            delay(12); //12mili approx 89Herz, speed pf my hx711 (not 80 but 89 is my speed)

            if (flag_init_time == 1) //first time we use time_delta=0;
            {
                time_delta = 0;
                t_simulate = millis(); //here we set the reference time
                case_counter = 0;
            }
            else
            {
                time_delta = abs(millis() - t_simulate);
            }

            if (time_delta >= timeperiode00 * case_counter && time_delta < timeperiode01 * (case_counter + 1))
            {
                loadcellraw = mapping(load_table[case_counter], 0, 100.0, min_break, max_break); //mapping
                flag_init_time = 0;
            }
            else
            {
                case_counter++;
            }

            if (time_delta >= tpmax)
            {
                flag_init_time = 1;
            }
        }

        loadcellcleaned = loadcellraw;
        count++;

        if (count > 1000000)
        {
            count = 0;
        }

        bitcheckfloat(loadcellcleaned, min_break, max_break); //cannot be less the min_break and not bigger then max_break

        /*
        //if max_break more then max_break it cant be more then max_break
        if (loadcellcleaned > max_break)
        {
            loadcellcleaned = max_break;
        }

        //if min_break less then min_break it cant be less then min_break
        if (loadcellcleaned < min_break)
        {
            loadcellcleaned = min_break;
        }
        */

        if (normal == 0)
        {
            // calulate the dac value for this case
            GLED = calulate_dac_raw(loadcellcleaned);

            //trasfare global variable in a safe way for the task part
            xSemaphoreTake(Semaphore, portMAX_DELAY);
            GLED_global = GLED;
            count;
            normalization = normal;
            open2use = true;
            xSemaphoreGive(Semaphore);
            vTaskDelay(2);

            if (millis() > t + serialPrintInterval)
            {
                if (SerialPrintData == 1)
                {
                    SerialPrintOutCollector(count, loadcellraw, GLED, 0, 0, 0, 1);
                }

                t = millis();
            }
        }
        else if (normal == 1)
        {
            float weight_in_percent;
            int lower_bit_case;
            int upper_bit_case;
            int lower_pwm;
            int upper_pwm;
            int dac_case = 0;

            // calulate the dac value for this case
            calculate_dac_normalizated(loadcellcleaned, weight_in_percent, lower_bit_case, upper_bit_case, lower_pwm, upper_pwm, dac_case);

            //trasfare global variable in a safe way for the task part
            // ################### DAC PART ##########################################
            // ################### This as Task Part ##########################################
            xSemaphoreTake(Semaphore, portMAX_DELAY);
            lowerbitcase = lower_bit_case;
            upperbitcase = upper_bit_case;
            lower2pwm = lower_pwm;
            upper2pwm = upper_pwm;
            count;
            normalization = normal;
            //SerialPrintDataGlobal = SerialPrintData;
            //loadcellrawglobal = loadcellraw;
            //weight_in_percent_global = weight_in_percent;
            //gammafac_global = gammafac;
            dac_case_global = dac_case;
            open2use = true;
            xSemaphoreGive(Semaphore);
            vTaskDelay(2);

            //Serial.println(lower_bit_case);
            //Serial.print(" ");

            if (millis() > t + serialPrintInterval)
            {
                if (SerialPrintData == 1)
                {
                    SerialPrintOutCollector(count, loadcellraw, lower_bit_case, normal, gammafac, weight_in_percent, 2);
                }

                t = millis();
            }
        }

        newDataReady = 0;
    }

    if (reboot_esp32 == true) //mqtt command to reboot esp32
    {
        print_serial_and_bt("", 1);
        print_serial_and_bt("Reboot ESP32 in 2 sec.", 0);
        print_serial_and_bt("", 1);

        delay(2000);          // 5 sec on display
        reboot_esp32 = false; //make no sence since it will reboot but anyway
        ESP.restart();
    }

    //check if some input from command line also for blue tooth
    serial_available();
}
